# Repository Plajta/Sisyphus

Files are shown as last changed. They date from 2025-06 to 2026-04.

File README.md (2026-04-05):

# Sisyphus
This repository includes the hardware, firmware, chassis and documentation for our soundboard helping those who need it (or don't and want a thing that makes sounds).

Code for the firmware's web configurator (Lithos) can be found [here](https://github.com/Plajta/lithos).

## Key features
Built using open source software on widely documented hardware.

With RP2040 as it's beating heart and a nice crisp I2S DAC, it can (but probably won't be used to) do CD quality audio.

Built into a strudy, but slim and relatively lite 3D printed construction, held together by friction and screws for ease of repair and construction. (construction manual coming soon™)

## Directory structure
- [3D](3D/) - FreeCAD project, the [STLs](3D/STLs) subdirectory includes the exported files ready for 3D printing
- [PCBs](PCBs/) - Two KiCAD projects, one for Sisyphus's [mainboard](PCBs/sisyphus) and one for our own slim [RGB sensor module](PCBs/rgb_sensor)
- [src](src/) - The board's firmware, has it's own README, also usable on a Raspberry Pi Pico with a bit of configuration

## Licensing
All main directories have their own LICENSE files.

`3D` and `PCBs` are under CC-BY-SA. `src` is licensed under GPL3.
That means you can use the whole thing, or just a part of it in your commercial projects but must publically share your potential changes under the same license.

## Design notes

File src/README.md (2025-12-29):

# Sisyphus firmware
And RP2040 firmware built mainly for SisyFOSS boards. Includes a filesystem, color processing, USB stack with a custom protocol and a keyboard driver!

As this firmware is mainly built for custom boards it doesn't provide a good experience on the default Pico, but it still can run there.

A linker script is used for building, that allowed us to make a separate part of the flash JUST for the LittleFS filesystem. This means there is no way for data loss when upgrading firmware!

This repository consists of the following:
- [Audio](audio/) - takes care of audio and it's loading - built from [RPi's code](https://github.com/raspberrypi/pico-playground/blob/master/audio/sine_wave/sine_wave.c)
- [Battery management](battery/) - drivers for BMS chips
- [Boards](boards/) - headers for supported boards
- [Color](color/) - drivers for color sensors, color management, color LUT
- [Eternity](https://github.com/Plajta/eternity) - submodule - our custom built 3rd stage bootloader for the RP2040
- [Keyboard](keyboard/) - drivers for keyboard driver ICs
- [LittleFS](https://github.com/littlefs-project/littlefs) - submodule - an amazing small fail-safe filesystem for microcontrollers.
- [Protocol](protocol/) - a custom protocol for file management, diagnostics and setup
- [USB](usb/) - just TinyUSB headers
- [Util](util/) - misc stuff, setup for LittleFS for the RP2040, ARGB LED color indicator

## Installation
If you want to build the firmware yourself look [here](#building).

Github actions automatically builds the newest commit in three different versions:
1. Pico - meant for the RPi Pico - mainly for testing
2. Pico + Eternity - Also for the Pico, but includes our bootloader Eternity - also for testing
3. SisyFOSS - meant for the SisyFOSS β board, already includes Eternity
To install the normal Pico firmware just flash the `sisyphus.uf2`.

Builds with included Eternity can be flashed in two ways:
1. By flashing `combined.uf2` the normal way.
2. If your board already has Eternity on it, you can flash the `sisyphus.bin` file using the web interface included in this repository (WIP) or with [Eternity's flasher](https://github.com/Plajta/eternity/blob/main/protocol/flasher.py).

## Usage
The primary way of interacting with this firmware is using a [web interface](https://lithos.plajta.eu/) ([code](https://github.com/Plajta/lithos)).

If you want to take a look inside or just want to do it yourself, look inside in the [Protocol](protocol/) directory for its README and a bunch of interesting scripts.

## Building
Building was only tested on Linux, it might work elsewhere but only to a limited extent.

If you don't already know what software you need to build a pico-sdk project you can take a look at RPi's excellent docs [1](https://datasheets.raspberrypi.com/pico/getting-started-with-pico.pdf), [2](https://www.raspberrypi.com/documentation/microcontrollers/c_sdk.html#quick-start-your-own-project), for parts that talk about installing the toolchain.

First make sure you have your git submodules up to date. This will automatically clone [Eternity](https://github.com/Plajta/eternity)'s and [LittleFS](https://github.com/littlefs-project/littlefs)'s code.
```bash
git submodule update --init --recursive
```

Now create a `build` directory:
```bash
mkdir build
```
This is already where it gets a little bit complicated but stick with me. Since this firmware is mainly built for SisyFOSS boards we have to specifically say we want to build the firmware for them.
In the example below I picked the Sisyfoss β board. If you also want to include Eternity you have to specifically tell `cmake` to do that. Of course if you don't want either of those things just delete them.
```bash
cmake -DPICO_BOARD=plajta_sisyfoss_beta -DUSE_ETERNITY=ON ..
```
This should produce a bunch of binaries, but the ones you are interested in are either `sisyphus.uf2` or `combined.uf2` with `sisyphus.bin`. Take a look at how to work with them in the [Installation](#installation) part.

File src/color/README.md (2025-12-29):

# Color subsystem
This directory contains the color sensor initialization and color processing code.

The code in [color.c](./color.c) is basically just a split-off part of [main.c](../main.c) so it's more readable.

Sisyphus uses a [color LUT](#color-lut) for choosing which sound it should play. Each color in that LUT has its assigned letter, which is used to determine a part of the played file's name.
Each color also optionally can have a representation to be shown using the ARGB LED indicator. This is useful for user feedback.

# Adding a new sensor
When adding a new sensor, copy over an already existing one (eg. VEML3328) and edit over that.
Don't forget to edit the sensor's `CMakeLists.txt` and add it to [sensors/CMakeLists.txt](sensors/CMakeLists.txt).

# Color LUT
Colors and their name codes are described here in this format:
```
<H> <S> <V> <color_code> <color_representation>\n
```
The color is defined in a HSV format because it is better suited for color matching during detection.
H, S and V are in a DECIMAL format, and are space separated.

Color code can be any letter of the alphabet, be sure to save this file in ASCII so you don't get any unicode characters in there and accidentally break it.

The color representation is optional but highly recommended for enhanced user visual feedback. It is written as a standard RGB hexadecimal value.
If no color representation is defined, a muted white will be used.

The line MUST be terminated by a newline, it wouldn't break the program but it WILL skip the line.
Lines longer than 21 characters will get ignored because they cannot be valid.

An example of a valid LUT can look like this:
```
22 44 55 r AA0000
86 22 47 g
281 6 41 b 0000AA
220 32 73 c 00AAAA
335 18 51 m AA00AA
65 42 74 y AAAA00
```
Notice `g` is missing it's color representation, that is still valid but discouraged.

The values you define here are compared against the measured color by calculating the difference (`measured_value - defined_value`) for each channel.
The entry that has the smallest overall difference is selected as the match.
In the future we may choose to ignore some channels, such as S or V, if they prove unnecessary for detection.

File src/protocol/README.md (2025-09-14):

# Sisyphus Protocol
Sisyphus firmware has its own protocol to communicate with the web interface.

***All of the scripts contained in this directory have 3rd party dependencies, you have been warned.***

This protocol doesn't have to be used only with the interface, this directory includes a [reference Python implementation](protocol.py) of the protocol that you are free to use for your own endeavors.
It also includes [full documentation](PROTOCOL.md) of the protocol that should be enough for you to write your own client. If it's not enough yell at me in the issues.

If you just want to access the device, you can also use a [handy shell](shell.py).

You can also use the [audio conversion script](convert.py) for loading your audio on your device.

There is also a [script](color_graph.py) originally meant for debugging the color sensor.

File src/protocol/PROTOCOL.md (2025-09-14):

# Sisyphus Protocol Documentation

Data is transmitted in **chunks of up to 1024 bytes**.

Commands are sent as strings, fields separated by spaces, terminated by **EOT** (`0x04`) character.

The device responds according to the specific command.

Errors are reported with messages starting with `err`, and successful operations respond with `ack`.

On invalid arguments:
  ```
  err invalid arguments
  ```
On overflow of the command buffer (128 bytes set in [protocol.h](./protocol.h)):
  ```
  err command buffer overflow
  ```

A handy python shell to test things out is [here](./shell.py), it uses `PySerial` wrapped in a backend package [here](./protocol.py) and also requires `rich` for nice color output.

Protocol version is incremented when there is a breaking change, it will NOT get incremented when eg. a new field in [info](#info) is added to the end.

---

## Command List

- [ls](#ls) - List files
- [mv](#mv) - Move (rename) a file
- [push](#push) - Upload a file to the device
- [pull](#pull) - Download a file from the device
- [rm](#rm) - Remove a file
- [info](#info) - Get information about the device and firmware
- [measure](#measure) - Get a color measurement from the device's color sensor
- [play](#play) - Play an audio file
- [reset](#reset) - Reset the device into bootloader

---

## `ls`

List files in the filesystem.

**Usage:**
```
ls
```

**Device response:**

Each file or directory is listed on a separate line:

```
<name> <type> <size>
```

- `<name>` - file or directory name
- `<type>` - `f` (file) or `d` (directory)
- `<size>` - size in bytes (only present for files)

**Example:**
```
readme.txt f 1234
data f 456
folder d
```

Terminated by EOT.

**Errors:**
- `err cannot open root directory`

---

## `mv`

Rename or move a file.

**Usage:**
```
mv <source> <destination>
```

**Device response:**
- `ack` - on success
- `err file not found` - if source doesn't exist
- `err destination exists` - if destination already exists
- `err rename file` - on failure

---

## `push`

Upload a file to the device.

**Usage:**
```
push <filename> <size> <checksum>
```

- `<size>` - file size in bytes
- `<checksum>` - expected CRC32 checksum (unsigned integer)

**Protocol:**

1. After `push` command, device sends:
   ```
   ack
   ```
2. Send the file data in chunks.
   - After each chunk, **wait for device to send** `ack` **before sending the next chunk**.
3. After all bytes are sent:
   - Device calculates CRC32 and verifies it against `<checksum>`.

**Errors:**
- `err open file`
- `err timeout`
- `err write file`
- `err checksum mismatch` (file deleted automatically on checksum mismatch)

---

## `pull`

Download a file from the device.

**Usage:**
```
pull <filename>
```

**Protocol:**

1. Device responds:
   ```
   ack <size> <checksum>
   ```
   - `<size>` - file size in bytes
   - `<checksum>` - CRC32 checksum

2. Host must immediately reply:
   ```
   ack
   ```

3. Device starts sending the file data in chunks.

4. After each chunk:
   - Host must send `ack` back to device to receive the next chunk.

5. Host should verify the received data against the expected checksum.

**Errors:**
- `err cannot open file`
- `err calculate crc`
- `err timeout`

---

## `rm`

Remove a file.

**Usage:**
```
rm <filename>
```

**Device response:**
- `ack` - if deleted successfully
- `err file not found`
- `err delete file` - if deletion failed

---

## `info`

Lists information about the device.

**Usage:**
```
info
```

**Device response:**
```
<protocol> <device name> <git commit sha> <protocol version> <build date> <block count> <free block count> <block size> <uses eternity> <debug mode>
```

- `<protocol>` - Always `sisyphus`
- `<device name>` - Name of the device set by CMakeLists.txt
- `<git commit sha>` - Git commit SHA at compile time, when compiled from a repository with uncommitted changes `-dirty` gets appended behind it
- `<protocol version>` - Version of the protocol set in [protocol.h](./protocol.h)
- `<build date>` - Date and time of the firmware build in `YYYY-MM-DD,HH:MM:SS`
- `<block count>` - Number of blocks taken up by LittleFS - total size set in CMakeLists.txt
- `<free block count>` - Number of free/unused blocks in LittleFS
- `<block size>` - Size of each block of LittleFS
- `<uses eternity>` - If the FW was built with Eternity's bootloader
- `<debug mode>` - Shows if debug mode is on, if developing a user-friendly frontend make it VERY clear that this is NOT `true` so devs don't accidentally ship a debug device.

Terminated by a newline.

Example:

```
sisyphus 7b82af1-dirty 1 2025-05-05,00:45:02 256 2 4096 1
```

---

## `measure`

Get a color measurement from the device's color sensor. These are the actual values used for color detection with all color processing included.

**Usage:**
```
measure
```

**Device response:**
```
<hue> <saturation> <value> <clear>
```

- `<hue>` - 0-360 - hue in degrees
- `<saturation>` - 0-100 - saturation as a percentage
- `<value>` - 0-100 - value as a percentage
- `<clear>` - 0-255 - brightness in a 8 bit range

Terminated by a newline.

Example:

```
4 56 33 17
```

---

## `play`

Play an audio file stored on the device.

**Usage:**
```
play <filename>
```

**Response:**
- `ack` - if file played successfully
- `err file not found` - if the file does not exist

---

## `reset`

Resets the device into either the bootrom or Eternity, based on CMake configuration.

**Usage:**

```
reset
```

**Device response:**

* None (device resets and reboots into USB bootloader)

---

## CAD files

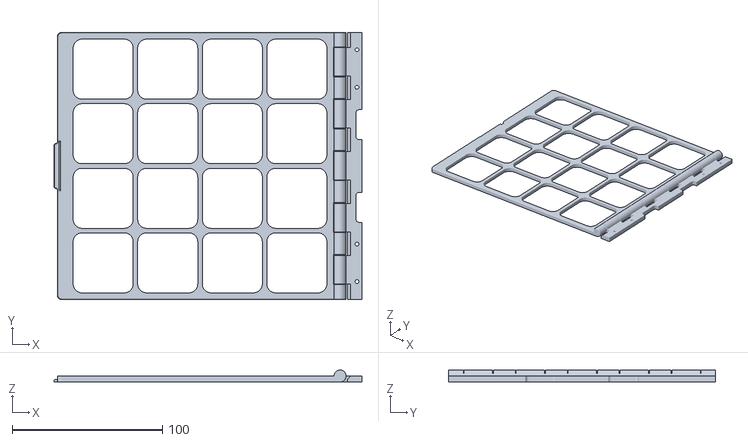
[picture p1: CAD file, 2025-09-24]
3D/STLs/sisyphus-Assembled-Hinge-Lid.stl
205.2 x 178.0 x 8.00

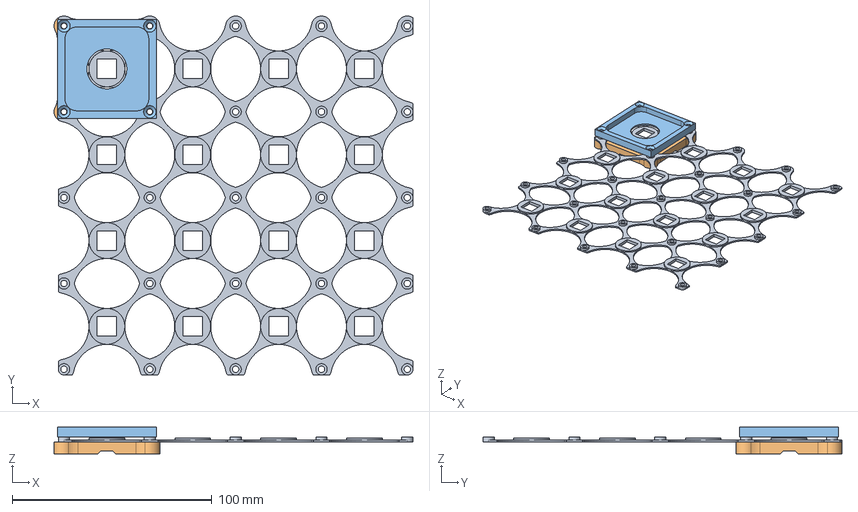
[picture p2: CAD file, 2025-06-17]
3D/sisyphus.FCStd
179.8 x 179.9 x 13.5 mm
Spring
Core
Top

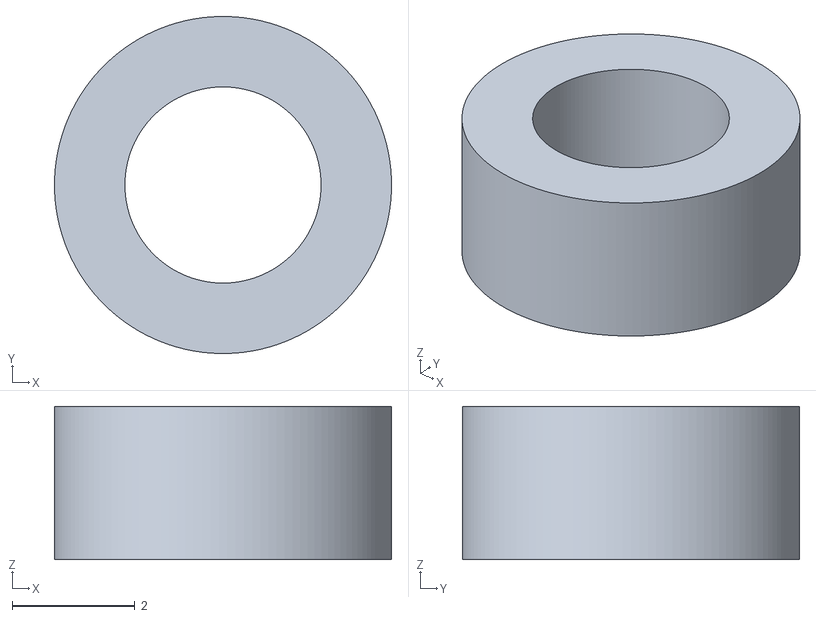
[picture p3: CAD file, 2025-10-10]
3D/STLs/sisyphus-M3_spacer.stl
5.50 x 5.50 x 2.50

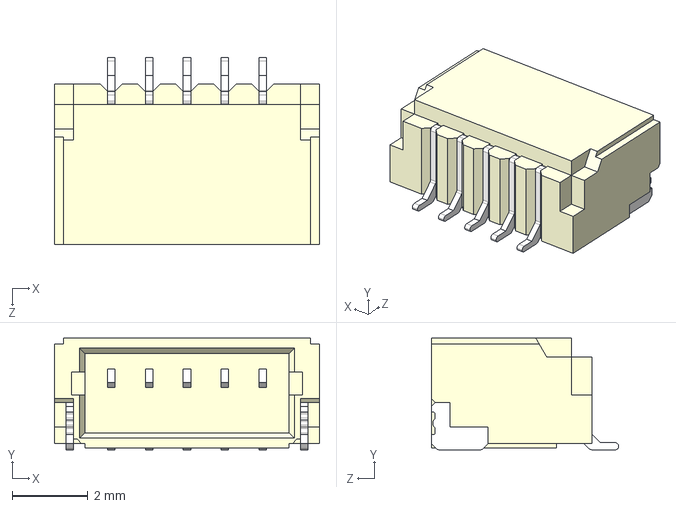
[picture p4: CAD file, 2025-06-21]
PCBs/rgb_sensor/rgb_sensor_3d/SM05B-SRSS-TB/SM05B-SRSS-TB.STEP
7.00 x 2.95 x 4.95 mm

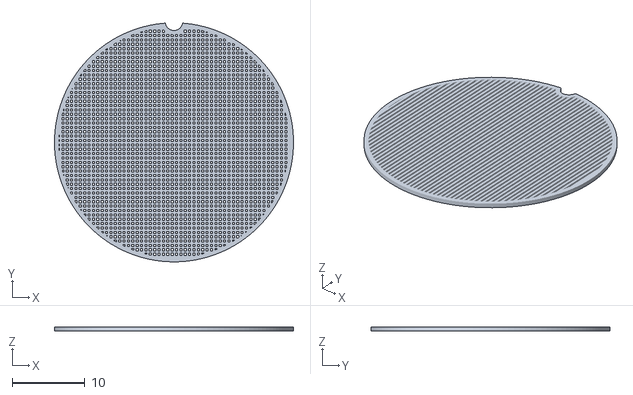
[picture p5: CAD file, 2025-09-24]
3D/STLs/sisyphus-Grille.stl
32.8 x 32.8 x 0.6

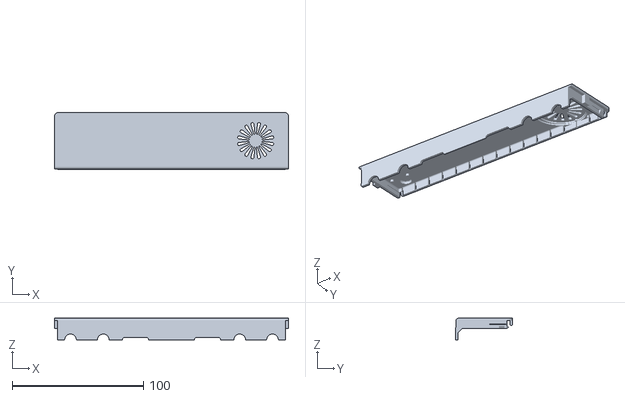
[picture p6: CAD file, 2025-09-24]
3D/STLs/sisyphus-Top_Cover.stl
178.4 x 43.7 x 16.6

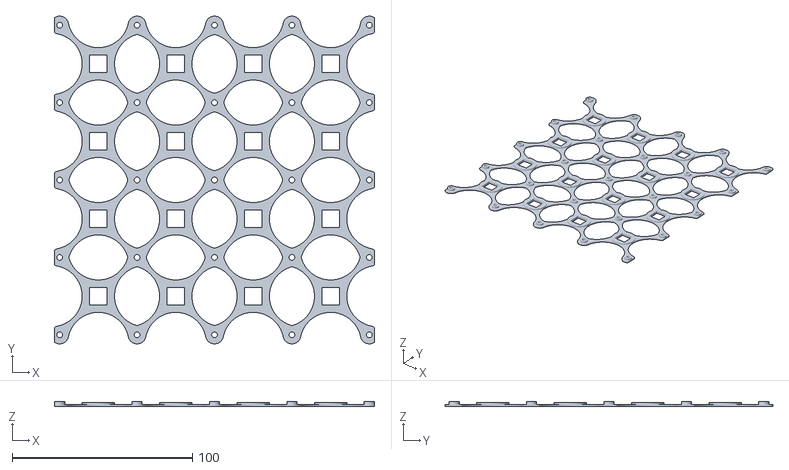
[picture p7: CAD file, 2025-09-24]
3D/STLs/sisyphus-Spring.stl
177.7 x 182.0 x 2.50

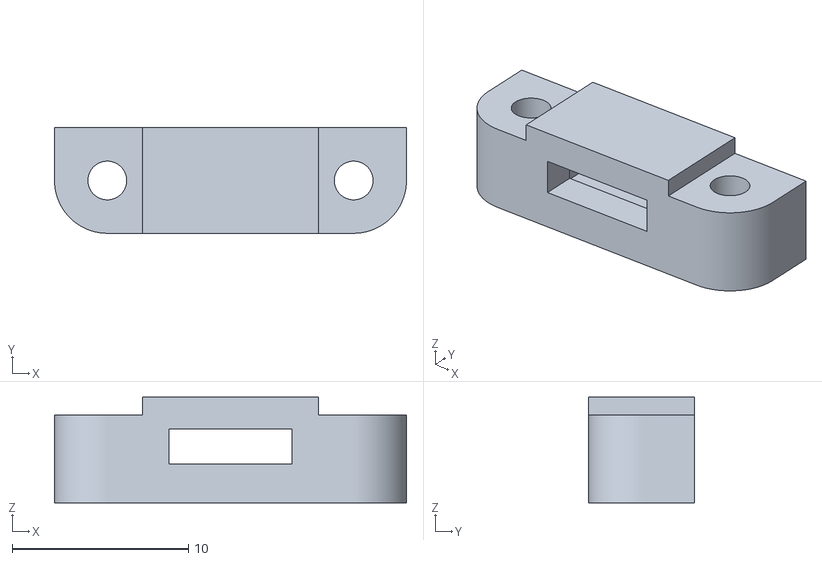
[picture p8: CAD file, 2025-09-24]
3D/STLs/sisyphus-Switch_holder.stl
20.0 x 6.00 x 6.00

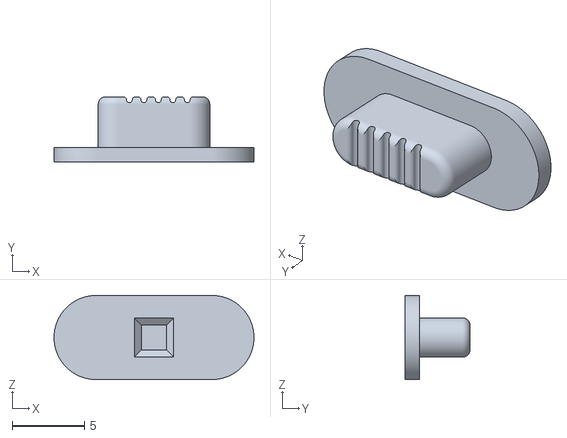
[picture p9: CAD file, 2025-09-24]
3D/STLs/sisyphus-Switch.stl
13.8 x 4.50 x 5.80

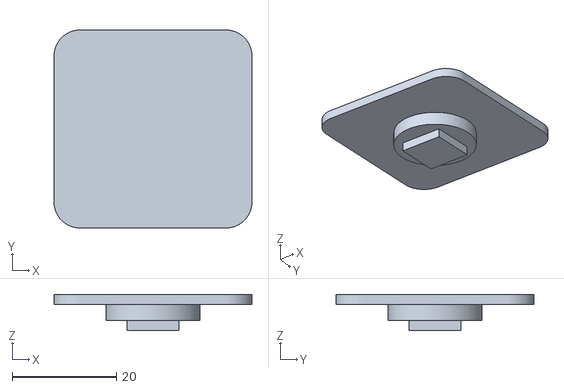
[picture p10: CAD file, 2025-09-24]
3D/STLs/sisyphus-Key_Cap.stl
38.0 x 38.0 x 7.00

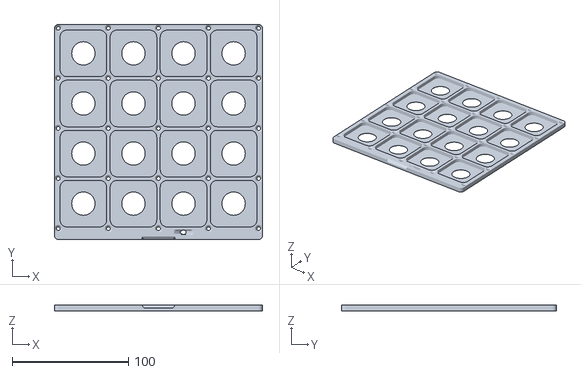
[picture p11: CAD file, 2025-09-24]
3D/STLs/sisyphus-Top.stl
178.6 x 184.6 x 5.00

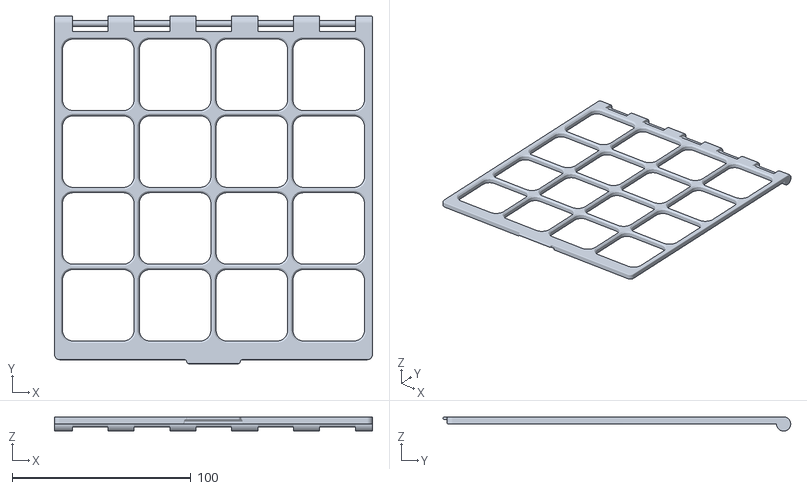
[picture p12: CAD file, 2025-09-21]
3D/STLs/sisyphus-Lid.stl
178.0 x 194.5 x 8.00

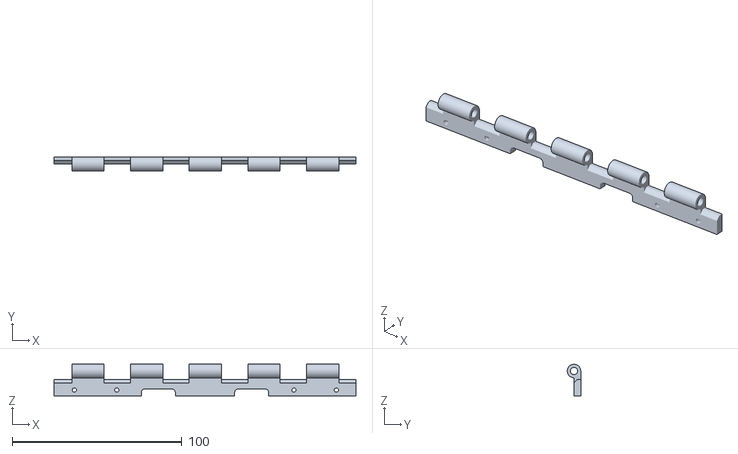
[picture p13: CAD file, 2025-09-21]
3D/STLs/sisyphus-Hinge.stl
178.0 x 8.00 x 18.6

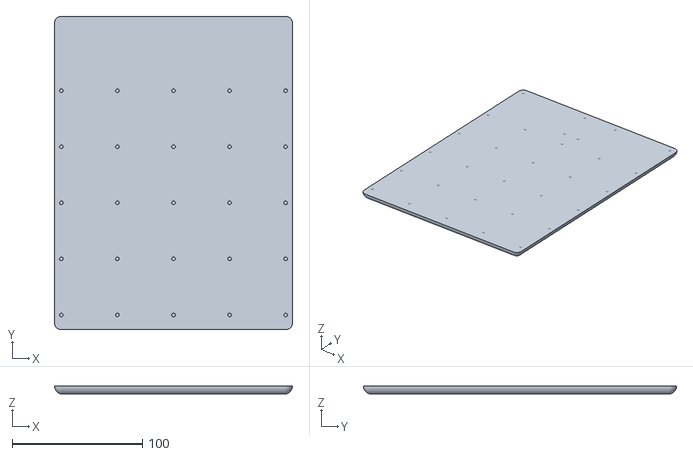
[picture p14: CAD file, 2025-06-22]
3D/STLs/sisyphus-Bottom.stl
182.5 x 240.2 x 6.50

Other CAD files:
PCBs/rgb_sensor/rgb_sensor_3d/VEML3328/80216oplga4l.stp

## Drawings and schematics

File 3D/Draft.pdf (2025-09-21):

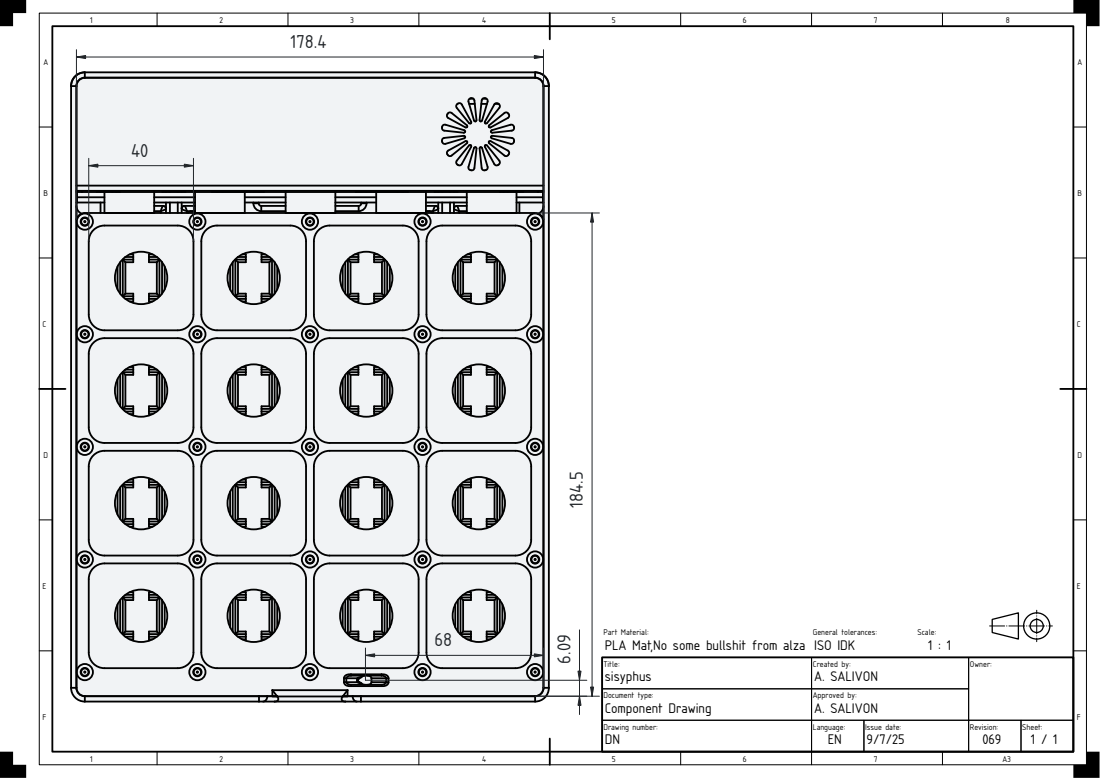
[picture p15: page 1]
Part Material:; General tolerances:; Scale:; PLA Mat,No some bullshit from alza ISO IDK

Title: sisyphus | Created by: A. SALIVON | Owner:

Document type: Component Drawing | Approved by: A. SALIVON

Drawing number: DN | Language: EN | Issue date: 9/7/25 | Revision: 069 | Sheet: 1 / 1

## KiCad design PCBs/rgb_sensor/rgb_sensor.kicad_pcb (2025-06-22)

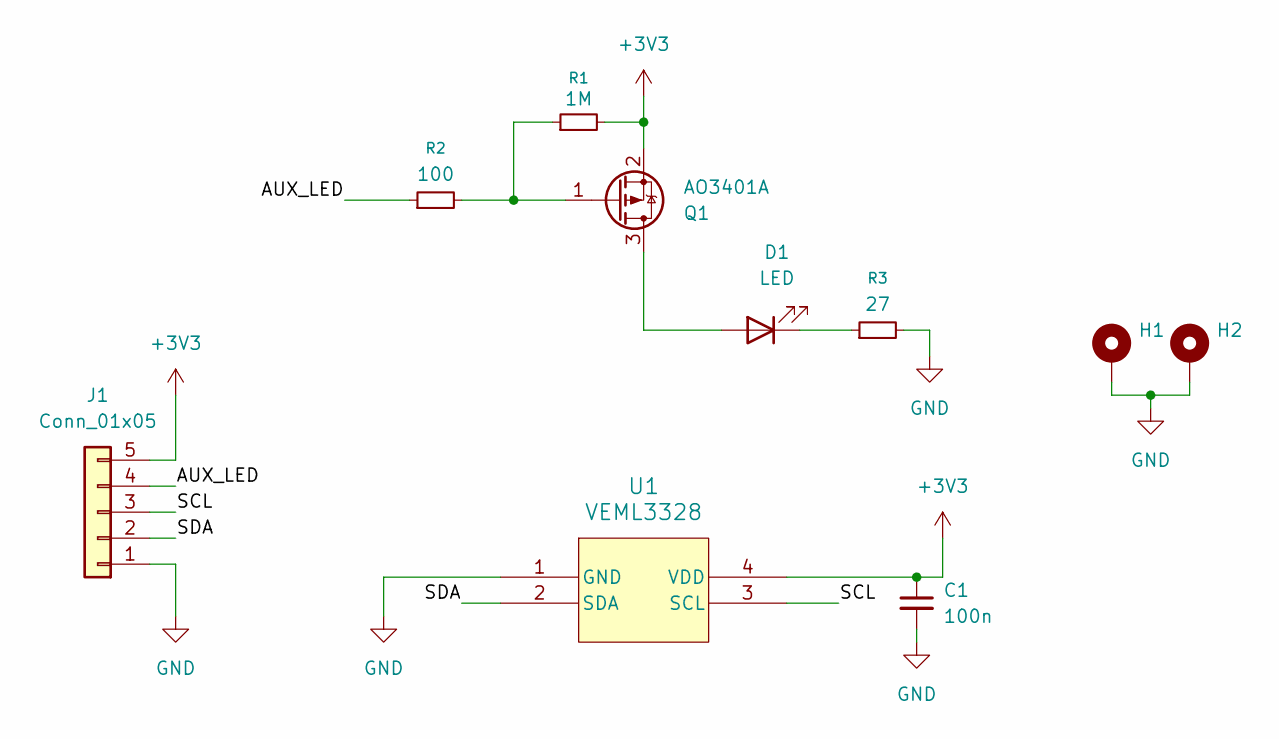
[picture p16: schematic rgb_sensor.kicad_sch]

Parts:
C1: 100n; C_0402_1005Metric
D1: LED; LED_0805_2012Metric
H1, H2: MountingHole_Pad; MountingHole_2.2mm_M2_Pad
J1: Conn_01x05; JST_SH_SM05B-SRSS-TB_1x05-1MP_P1.00mm_Horizontal
Q1: AO3401A; SOT-23
R1: 1M; R_0402_1005Metric
R2: 100; R_0402_1005Metric
R3: 27; R_0402_1005Metric
U1: VEML3328; SMD_L3328_VIS

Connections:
+3V3: C1.1, J1.5, Q1.2 (S), R1.2, U1.4 (VDD)
/AUX_LED: J1.4, R2.1
/SCL: J1.3, U1.3 (SCL)
/SDA: J1.2, U1.2 (SDA)
GND: C1.2, H1.1, H2.1, J1.1, R3.2, U1.1 (GND)
unnamed: D1.2 (A), Q1.3 (D)
unnamed: D1.1 (K), R3.1
unnamed: Q1.1 (G), R1.1, R2.2

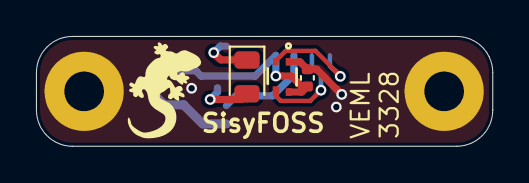
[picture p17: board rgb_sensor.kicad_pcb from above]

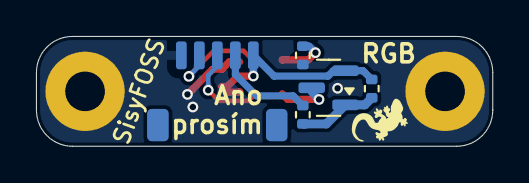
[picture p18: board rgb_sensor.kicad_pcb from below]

Board: 2 copper layers, 25.3 x 6.1 mm, 10 parts (5 on the bottom side), 8 nets.

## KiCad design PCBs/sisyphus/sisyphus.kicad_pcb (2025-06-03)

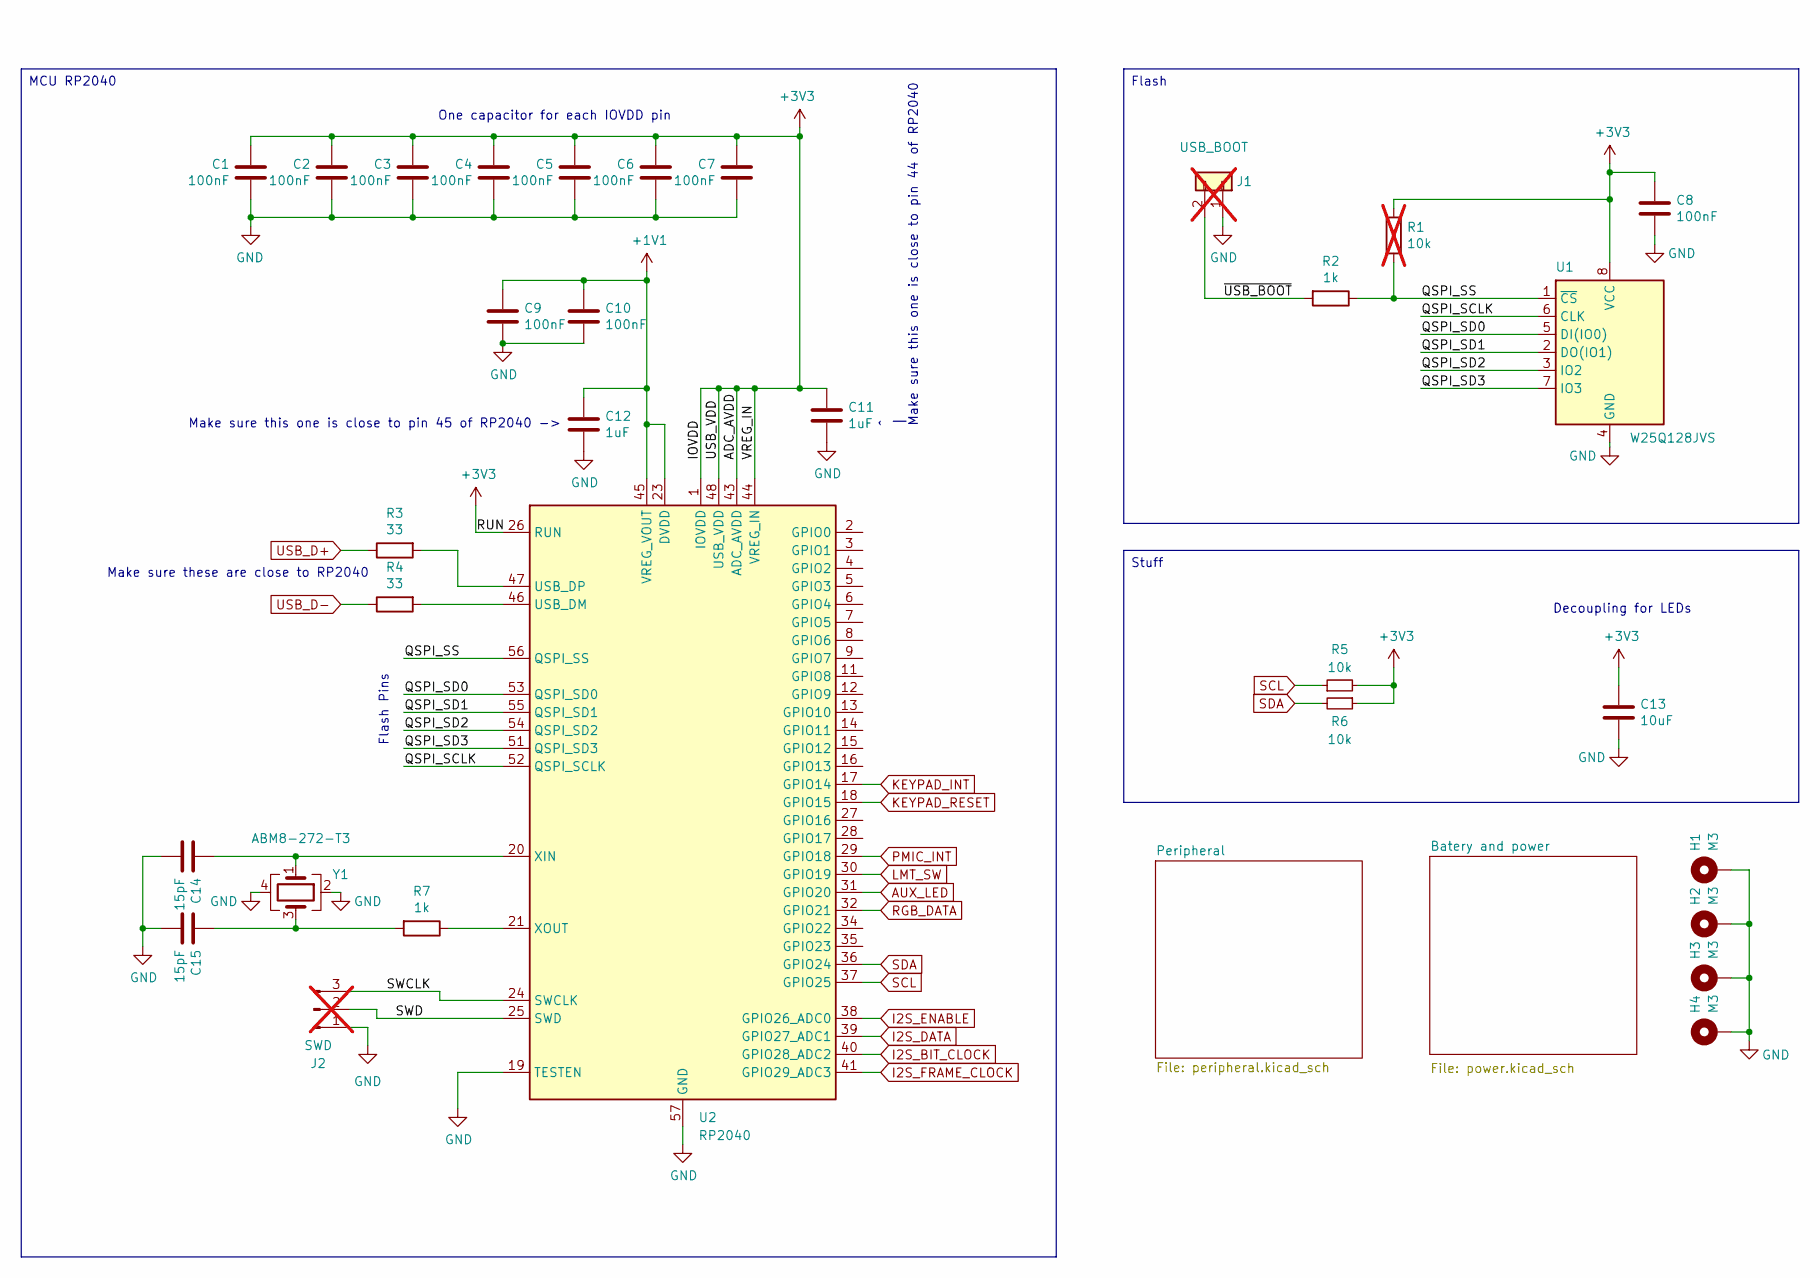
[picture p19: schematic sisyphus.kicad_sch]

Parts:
C1, C2, C3, C4, C5, C6, C7, C8, C9, C10: 100nF; C_0402_1005Metric
C11, C12: 1uF; C_0402_1005Metric
C13: 10uF; C_0402_1005Metric
C14, C15: 15pF; C_0402_1005Metric
H1, H2, H3, H4: M3; MountingHole_3.2mm_M3_ISO7380_Pad
J1: USB_BOOT; PinHeader_1x02_P2.54mm_Vertical; not fitted
J2: SWD; PinHeader_1x03_P2.54mm_Vertical; not fitted
R1: 10k; R_0402_1005Metric; not fitted
R2, R7: 1k; R_0402_1005Metric
R3, R4: 33; R_0402_1005Metric
R5, R6: 10k; R_0402_1005Metric
U1: W25Q128JVS; SOIC-8_5.23x5.23mm_P1.27mm
U2: RP2040; QFN-56-1EP_7x7mm_P0.4mm_EP3.2x3.2mm
Y1: ABM8-272-T3; Crystal_SMD_3225-4Pin_3.2x2.5mm

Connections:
+1V1: C9.1, C10.1, C12.1, U2.23 (DVDD), U2.45 (VREG_VOUT), U2.50 (DVDD)
+3V3: C1.1, C2.1, C3.1, C4.1, C5.1, C6.1, C7.1, C8.1, C11.1, C13.1, R1.1, R5.2, R6.1, U1.8 (VCC), U2.1 (IOVDD), U2.10 (IOVDD), U2.22 (IOVDD), U2.26 (RUN), U2.33 (IOVDD), U2.42 (IOVDD), U2.43 (ADC_AVDD), U2.44 (VREG_IN), U2.48 (USB_VDD), U2.49 (IOVDD); also elsewhere on the board
/QSPI_SCLK: U1.6 (CLK), U2.52 (QSPI_SCLK)
/QSPI_SD0: U1.5 (DI(IO0)), U2.53 (QSPI_SD0)
/QSPI_SD1: U1.2 (DO(IO1)), U2.55 (QSPI_SD1)
/QSPI_SD2: U1.3 (IO2), U2.54 (QSPI_SD2)
/QSPI_SD3: U1.7 (IO3), U2.51 (QSPI_SD3)
/QSPI_SS: R1.2, R2.1, U1.1 (~CS), U2.56 (QSPI_SS)
/SWCLK: J2.3, U2.24 (SWCLK)
/SWD: J2.2, U2.25 (SWD)
/~USB_BOOT: J1.2, R2.2
AUX_LED: U2.31 (GPIO20); also elsewhere on the board
GND: C1.2, C2.2, C3.2, C4.2, C5.2, C6.2, C7.2, C8.2, C9.2, C10.2, C11.2, C12.2, C13.2, C14.2, C15.2, H1.1, H2.1, H3.1, H4.1, J1.1, J2.1, U1.4 (GND), U2.19 (TESTEN), U2.57 (GND), Y1.2, Y1.4; also elsewhere on the board
I2S_BIT_CLOCK: U2.40 (GPIO28_ADC2); also elsewhere on the board
I2S_DATA: U2.39 (GPIO27_ADC1); also elsewhere on the board
I2S_ENABLE: U2.38 (GPIO26_ADC0); also elsewhere on the board
I2S_FRAME_CLOCK: U2.41 (GPIO29_ADC3); also elsewhere on the board
KEYPAD_INT: U2.17 (GPIO14); also elsewhere on the board
KEYPAD_RESET: U2.18 (GPIO15); also elsewhere on the board
LMT_SW: U2.30 (GPIO19); also elsewhere on the board
unnamed: C15.1, R7.2, Y1.3
unnamed: R4.2, U2.46 (USB_DM)
unnamed: R3.2, U2.47 (USB_DP)
unnamed: C14.1, U2.20 (XIN), Y1.1
unnamed: R7.1, U2.21 (XOUT)
PMIC_INT: U2.29 (GPIO18); also elsewhere on the board
RGB_DATA: U2.32 (GPIO21); also elsewhere on the board
SCL: R5.1, U2.37 (GPIO25); also elsewhere on the board
SDA: R6.2, U2.36 (GPIO24); also elsewhere on the board
USB_D+: R3.1; also elsewhere on the board
USB_D-: R4.1; also elsewhere on the board

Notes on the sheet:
Make sure this one is close to pin 45 of RP2040 ->
Decoupling for LEDs
Make sure these are close to RP2040
One capacitor for each IOVDD pin
^ | Make sure this one is close to pin 44 of RP2040
Flash Pins
Flash
MCU RP2040
Stuff

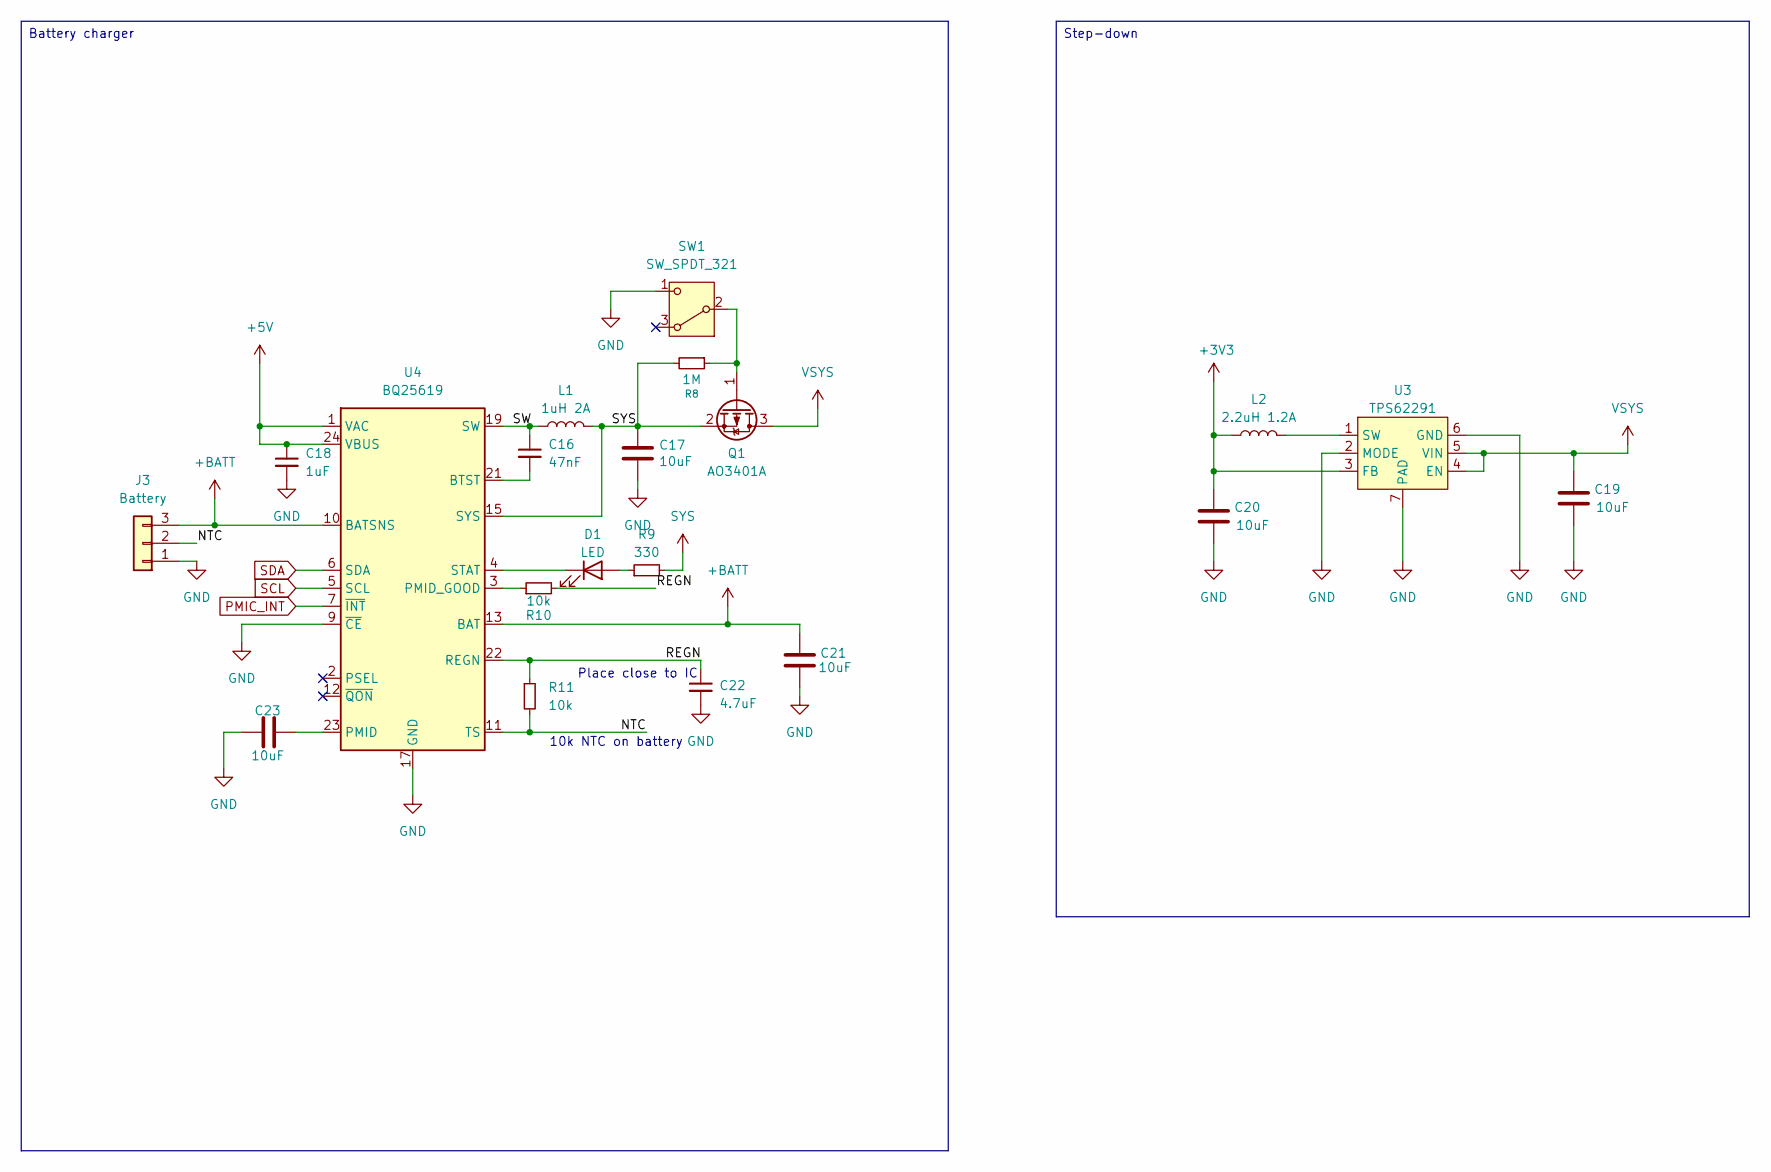
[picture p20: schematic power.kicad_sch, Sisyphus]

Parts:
C16: 47nF; C_0402_1005Metric
C17, C19, C20, C21, C23: 10uF; C_0402_1005Metric
C18: 1uF; C_0402_1005Metric
C22: 4.7uF; C_0402_1005Metric
D1: LED; LED_0603_1608Metric
J3: Battery; JST_PH_S3B-PH-SM4-TB_1x03-1MP_P2.00mm_Horizontal
L1: 1uH 2A; L_0603_1608Metric
L2: 2.2uH 1.2A; L_0805_2012Metric
Q1: AO3401A; SOT-23
R8: 1M; R_0402_1005Metric
R9: 330; R_0402_1005Metric
R10, R11: 10k; R_0402_1005Metric
SW1: SW_SPDT_321; PinHeader_1x03_P2.54mm_Vertical
U3: TPS62291; WSON-6-1EP_2x2mm_P0.65mm_EP1x1.6mm_ThermalVias
U4: BQ25619; Texas_RTW_WQFN-24-1EP_4x4mm_P0.5mm_EP2.7x2.7mm_ThermalVias

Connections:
+3V3: C20.1, L2.1, U3.3 (FB); also elsewhere on the board
+5V: C18.1, U4.1 (VAC), U4.24 (VBUS); also elsewhere on the board
+BATT: C21.1, J3.3, U4.10 (BATSNS), U4.13 (BAT), U4.14 (BAT)
/Batery and power/NTC: J3.2, R11.2, U4.11 (TS)
/Batery and power/REGN: C22.1, R10.2, R11.1, U4.22 (REGN)
/Batery and power/SW: C16.1, L1.1, U4.19 (SW), U4.20 (SW)
GND: C17.2, C18.2, C19.2, C20.2, C21.2, C22.2, C23.1, J3.1, SW1.1 (C), U3.2 (MODE), U3.6 (GND), U3.7 (PAD), U4.9 (~CE), U4.17 (GND), U4.18 (GND), U4.25 (GND); also elsewhere on the board
unnamed: D1.2 (A), R9.1
unnamed: D1.1 (K), U4.4 (STAT)
unnamed: Q1.1 (G), R8.1, SW1.2 (B)
unnamed: L2.2, U3.1 (SW)
unnamed: C16.2, U4.21 (BTST)
unnamed: C23.2, U4.23 (PMID)
unnamed: R10.1, U4.3 (PMID_GOOD)
PMIC_INT: U4.7 (~INT); also elsewhere on the board
SCL: U4.5 (SCL); also elsewhere on the board
SDA: U4.6 (SDA); also elsewhere on the board
SYS: C17.1, L1.2, Q1.2 (S), R8.2, R9.2, U4.15 (SYS), U4.16 (SYS)
VSYS: C19.1, Q1.3 (D), U3.4 (EN), U3.5 (VIN); also elsewhere on the board

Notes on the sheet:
Place close to IC
10k NTC on battery
Step-down
Battery charger

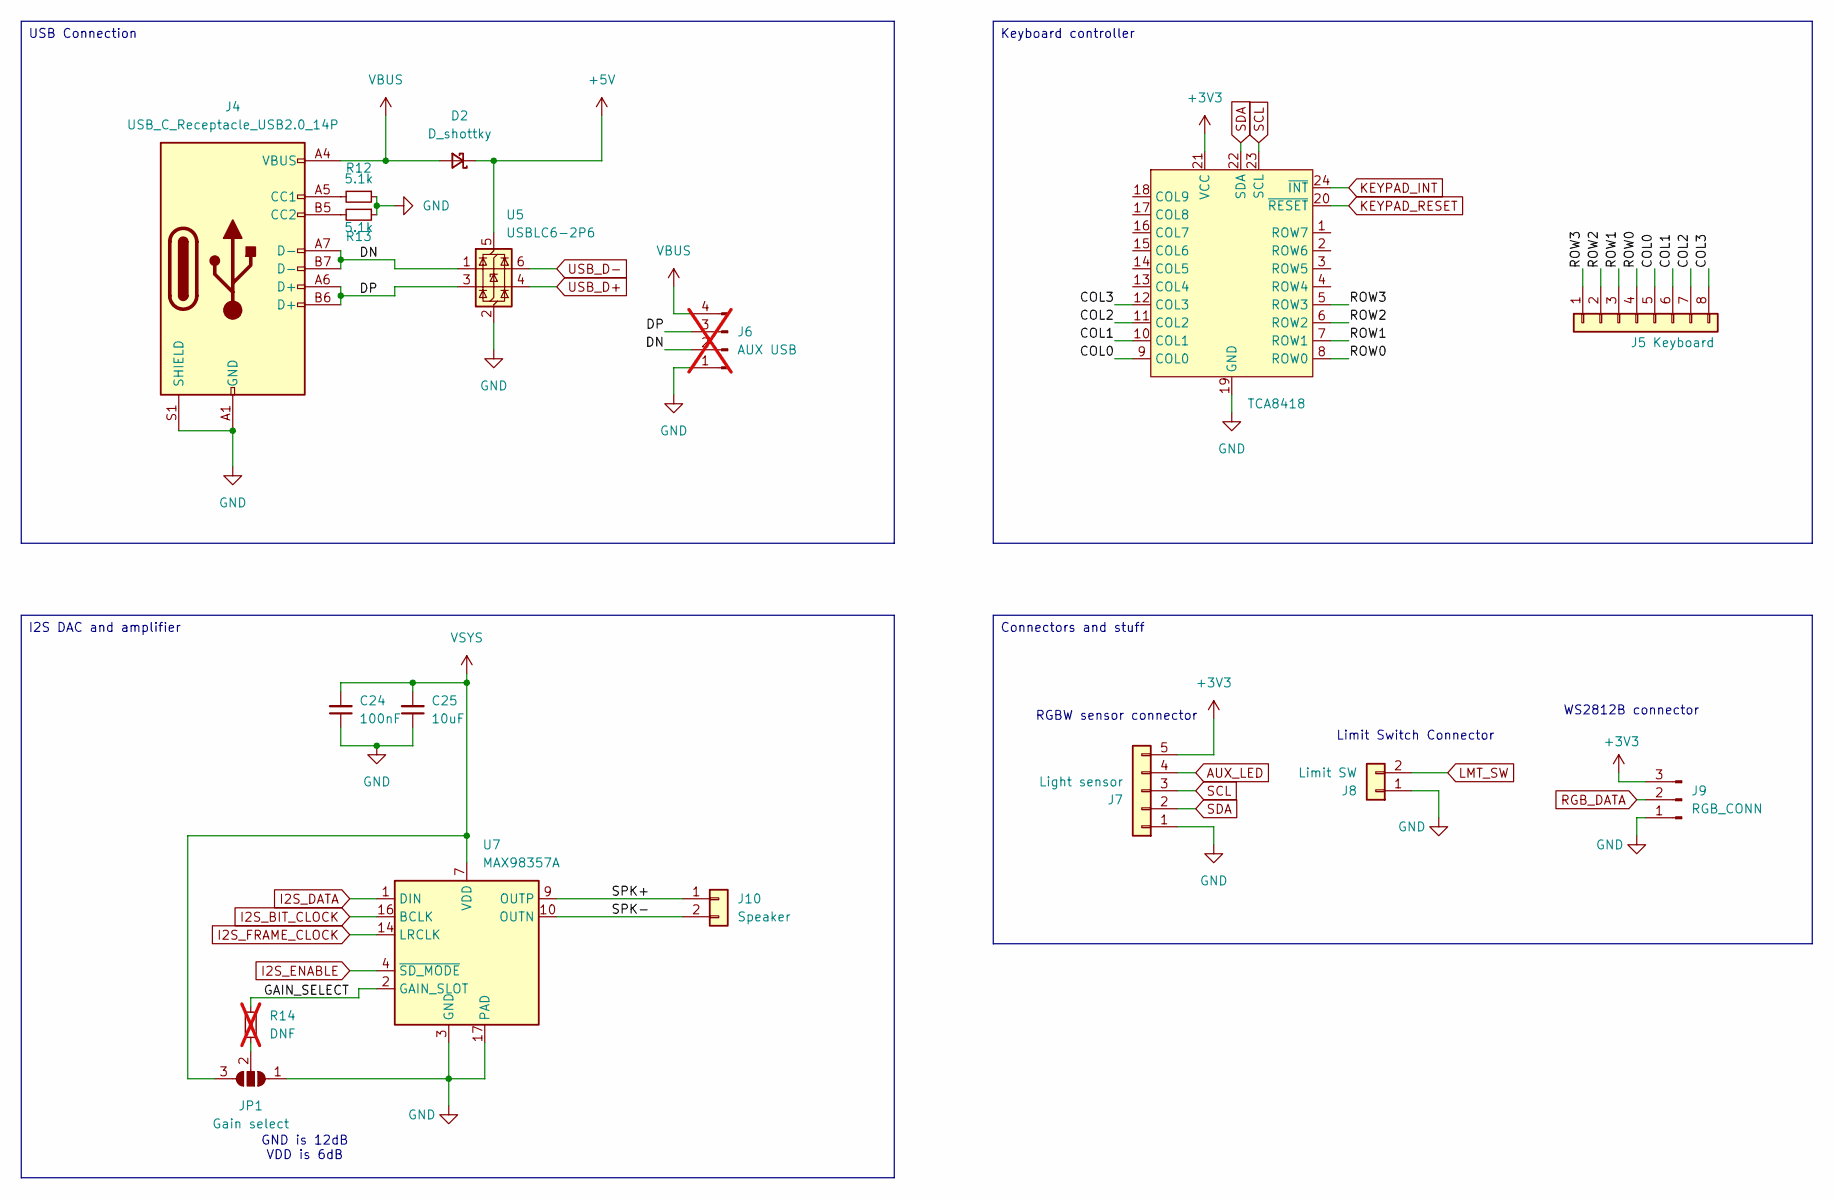
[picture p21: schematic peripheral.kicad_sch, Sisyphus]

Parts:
C24: 100nF; C_0402_1005Metric
C25: 10uF; C_0402_1005Metric
D2: D_shottky; D_SOD-123
J4: USB_C_Receptacle_USB2.0_14P; USB_C_Receptacle_G-Switch_GT-USB-7010ASV
J5: Keyboard; JST_XH_S8B-XH-A_1x08_P2.50mm_Horizontal
J6: AUX USB; PinHeader_1x04_P2.54mm_Vertical; not fitted
J7: Light sensor; JST_XH_S5B-XH-A_1x05_P2.50mm_Horizontal
J8: Limit SW; PinSocket_1x02_P2.54mm_Vertical
J9: RGB_CONN; PinHeader_1x03_P2.54mm_Vertical
J10: Speaker; PinHeader_1x02_P2.54mm_Vertical
JP1: Gain select; SolderJumper-3_P1.3mm_Open_RoundedPad1.0x1.5mm
R12, R13: 5.1k; R_0402_1005Metric
R14: DNF; R_0402_1005Metric; not fitted
U5: USBLC6-2P6; SOT-666
U6: TCA8418; WQFN-24-1EP_4x4mm_P0.5mm_EP2.45x2.45mm
U7: MAX98357A; TQFN-16-1EP_3x3mm_P0.5mm_EP1.23x1.23mm

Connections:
+3V3: J7.5, J9.3, U6.21 (VCC); also elsewhere on the board
+5V: D2.1 (K), U5.5 (VBUS); also elsewhere on the board
/Peripheral/COL0: J5.5, U6.9 (COL0)
/Peripheral/COL1: J5.6, U6.10 (COL1)
/Peripheral/COL2: J5.7, U6.11 (COL2)
/Peripheral/COL3: J5.8, U6.12 (COL3)
/Peripheral/DN: J4.A7 (D-), J4.B7 (D-), J6.2, U5.1 (I/O1)
/Peripheral/DP: J4.A6 (D+), J4.B6 (D+), J6.3, U5.3 (I/O2)
/Peripheral/GAIN_SELECT: R14.1, U7.2 (GAIN_SLOT)
/Peripheral/ROW0: J5.4, U6.8 (ROW0)
/Peripheral/ROW1: J5.3, U6.7 (ROW1)
/Peripheral/ROW2: J5.2, U6.6 (ROW2)
/Peripheral/ROW3: J5.1, U6.5 (ROW3)
/Peripheral/SPK+: J10.1, U7.9 (OUTP)
/Peripheral/SPK-: J10.2, U7.10 (OUTN)
AUX_LED: J7.4; also elsewhere on the board
GND: C24.1, C25.1, J4.A1 (GND), J4.A12 (GND), J4.B1 (GND), J4.B12 (GND), J4.S1 (SHIELD), J6.1, J7.1, J8.1, J9.1, JP1.1 (A), R12.1, R13.1, U5.2 (GND), U6.19 (GND), U6.25 (PAD), U7.3 (GND), U7.11 (GND), U7.15 (GND), U7.17 (PAD); also elsewhere on the board
I2S_BIT_CLOCK: U7.16 (BCLK); also elsewhere on the board
I2S_DATA: U7.1 (DIN); also elsewhere on the board
I2S_ENABLE: U7.4 (~SD_MODE); also elsewhere on the board
I2S_FRAME_CLOCK: U7.14 (LRCLK); also elsewhere on the board
KEYPAD_INT: U6.24 (~INT); also elsewhere on the board
KEYPAD_RESET: U6.20 (~RESET); also elsewhere on the board
LMT_SW: J8.2; also elsewhere on the board
unnamed: J4.A5 (CC1), R12.2
unnamed: J4.B5 (CC2), R13.2
unnamed: JP1.2 (C), R14.2
RGB_DATA: J9.2; also elsewhere on the board
SCL: J7.3, U6.23 (SCL); also elsewhere on the board
SDA: J7.2, U6.22 (SDA); also elsewhere on the board
USB_D+: U5.4 (I/O2); also elsewhere on the board
USB_D-: U5.6 (I/O1); also elsewhere on the board
VBUS: D2.2 (A), J4.A4 (VBUS), J4.A9 (VBUS), J4.B4 (VBUS), J4.B9 (VBUS), J6.4
VSYS: C24.2, C25.2, JP1.3 (B), U7.7 (VDD), U7.8 (VDD); also elsewhere on the board

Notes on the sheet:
GND is 12dB VDD is 6dB
WS2812B connector
Limit Switch Connector
RGBW sensor connector
Connectors and stuff
Keyboard controller
I2S DAC and amplifier
USB Connection

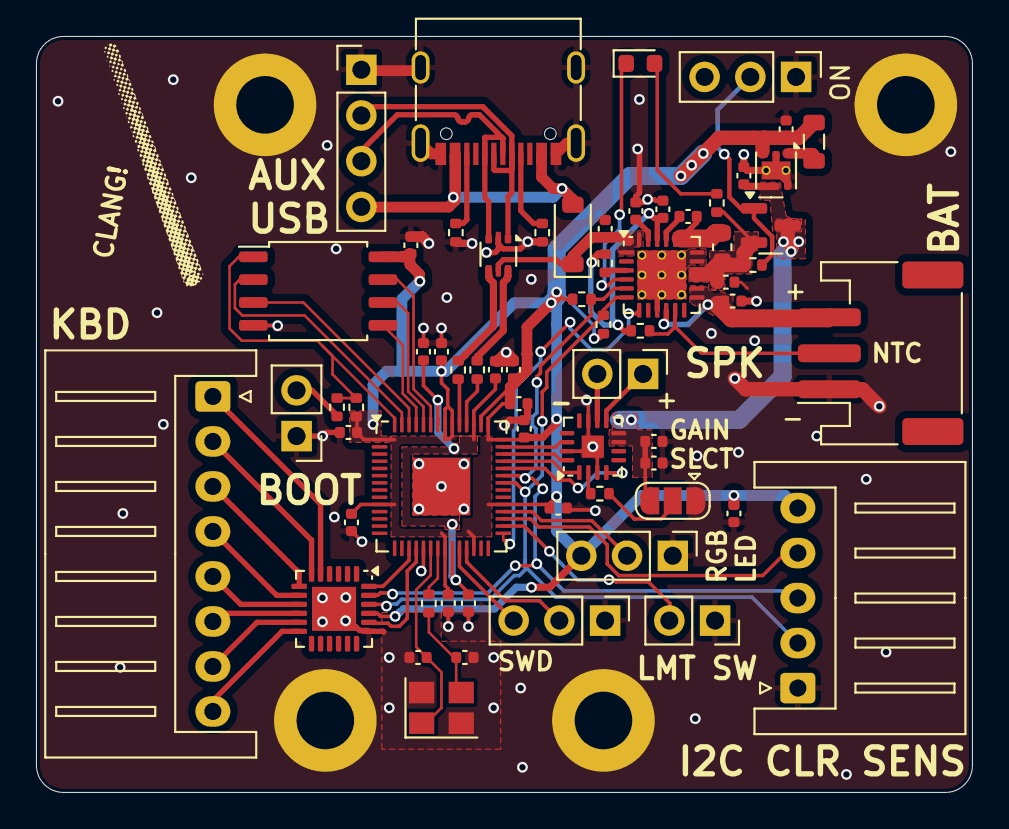
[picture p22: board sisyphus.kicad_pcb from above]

Board: 2 copper layers, 52.0 x 42.0 mm, 68 parts (0 on the bottom side), 62 nets.

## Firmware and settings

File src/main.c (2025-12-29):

#include <hardware/gpio.h>
#include <pico/error.h>
#include <pico/time.h>
#include <stdbool.h>
#include <stdio.h>
#include <bsp/board_api.h>
#include "bq25619.h"
#include "class/cdc/cdc_device.h"
#include "pico/binary_info.h" // IWYU pragma: keep
#include <tusb.h>
#include "protocol.h"
#include "hardware/i2c.h"
#include "audio.h"
#include "color.h"
#include "tca8418.h"
#include "ws2812.h"
#include "lightshow.h"

#include "littlefs-pico.h"

#define BUTTON_PIN 14

#ifdef SISYFOSS_I2S_ENABLE
bi_decl(bi_1pin_with_name(SISYFOSS_I2S_ENABLE, "I2S ENABLE"));
#endif

#if !defined(i2c_default) || !defined(PICO_DEFAULT_I2C_SDA_PIN) || !defined(PICO_DEFAULT_I2C_SCL_PIN)
#error Sisyphus requires a board with I2C pins
#endif

lfs_t lfs;

volatile bool wakeup = false;
volatile uint8_t button_index = 0;

volatile bool trigger_color_scan = false;
volatile bool trigger_audio = false;

static repeating_timer_t usb_timer;

struct color_matched_entry matched_color;
bool matched_color_valid = false;

i2c_inst_t *sisyfoss_i2c_inst = i2c_default;

static bool usb_background_task(repeating_timer_t *rt) {
    (void) rt;
    tud_task();  // TinyUSB background task
    return true; // Keep repeating
}

// Taken out so we can call it before loop and on trigger
void scan_color(){
    color_measurement color;
    color_read_sensor(&color);
    // 200 was just a shot i guessed and it seems to work, should probably be lowered
    // 170 is measured specifically for Sisyfoss's experimental 3D model right now, should be treated as a test number
    matched_color_valid = (color_lut_get_entry(&color, &matched_color, 200, 170) == PICO_OK);

    #ifdef PICO_DEFAULT_WS2812_PIN
    if (matched_color_valid){
        static lightshow_quartic_fade_state_t lightshow_state;

        lightshow_state.t = 0;
        lightshow_state.duration = 0.5;
        lightshow_state.reverse = false;
        lightshow_state.start_next_reversed = true;
        lightshow_state.base_color = matched_color.led_color_representation;

        lightshow_fade_setup(&lightshow_state);
    }
    #endif
}

void keyboard_interrupt() {
    if(!tca8418_k_int_available(sisyfoss_i2c_inst)){
        return;
    }

    uint8_t kbd_events = tca8418_num_events(sisyfoss_i2c_inst);

    // Re-check INT_STAT here (important per documentation)
    if (!tca8418_k_int_available(sisyfoss_i2c_inst)) {
        return;
    }

    uint8_t value;
    bool pressed;

    while (tca8418_num_events(sisyfoss_i2c_inst) > 0) {
        tca8418_get_key_from_fifo(sisyfoss_i2c_inst, &value, &pressed);
        button_index = value;
        if (pressed && !tud_cdc_connected()){
            wakeup = true;
            trigger_audio = true;
        }
    }

    // Clear the KE_INT interrupt bit by writing 1
    tca8418_k_int_reset(sisyfoss_i2c_inst);
}

void gpio_irq_dispatcher(uint gpio, uint32_t events){
    if (gpio == SISYFOSS_LID_DETECT && (events & GPIO_IRQ_EDGE_FALL)) {
        wakeup = true;
        trigger_color_scan = true;
    }
    else if (gpio == SISYFOSS_LID_DETECT && (events & GPIO_IRQ_EDGE_RISE)) {
        matched_color_valid = false;
    }
    #ifndef SISYFOSS_HAS_KEYBOARD_CONTROLLER
    else if (gpio == BUTTON_PIN && (events & GPIO_IRQ_EDGE_FALL)) {
        if(!tud_cdc_connected()){
            wakeup = true;
            button_index = 0;
        }
    }
    #else
    else if (gpio == SISYFOSS_KEYBOARD_INTERRUPT && (events & GPIO_IRQ_EDGE_FALL)) {
        keyboard_interrupt();
    }
    #endif
}

int main() {
    #ifdef PICO_DEFAULT_WS2812_PIN
    // First of all get the status LED, so errors can be shown
    int err = ws2812_init(PICO_DEFAULT_WS2812_PIN);
    hard_assert(err);
    #endif

    i2c_init(sisyfoss_i2c_inst, 100 * 1000);
    gpio_set_function(PICO_DEFAULT_I2C_SDA_PIN, GPIO_FUNC_I2C);
    gpio_set_function(PICO_DEFAULT_I2C_SCL_PIN, GPIO_FUNC_I2C);
    gpio_pull_up(PICO_DEFAULT_I2C_SDA_PIN);
    gpio_pull_up(PICO_DEFAULT_I2C_SCL_PIN);
    bi_decl(bi_2pins_with_func(PICO_DEFAULT_I2C_SDA_PIN, PICO_DEFAULT_I2C_SCL_PIN, GPIO_FUNC_I2C));
    bq25619_init(sisyfoss_i2c_inst); // init charger before all due safety reasons

    tusb_init();
    // Run tud_task every millisecond just like pico_stdio would do
    add_repeating_timer_ms(1, usb_background_task, NULL, &usb_timer);

    #ifdef SISYFOSS_I2S_ENABLE
    gpio_init(SISYFOSS_I2S_ENABLE);
    gpio_set_dir(SISYFOSS_I2S_ENABLE, GPIO_OUT);
    gpio_put(SISYFOSS_I2S_ENABLE, 1);
    #endif

    err = pico_lfs_init(&lfs);

    if (err) {
        sleep_ms(5000);
        return 0; // Todo add a color indicated error
    }

    init_audio();
    err = color_init();

    gpio_set_irq_callback(&gpio_irq_dispatcher);

    #ifndef SISYFOSS_HAS_KEYBOARD_CONTROLLER
    gpio_init(BUTTON_PIN);
    gpio_set_dir(BUTTON_PIN, GPIO_IN);
    gpio_pull_up(BUTTON_PIN);
    gpio_set_irq_enabled(BUTTON_PIN, GPIO_IRQ_EDGE_FALL, true);
    #else
    tca8418_init(sisyfoss_i2c_inst);
    tca8418_setup_keyboard(sisyfoss_i2c_inst, 0b1111, 0b1111);
    tca8418_setup_interrupt(&keyboard_interrupt);
    #endif

    #ifdef SISYFOSS_LID_DETECT
    gpio_init(SISYFOSS_LID_DETECT);
    gpio_set_dir(SISYFOSS_LID_DETECT, GPIO_IN);
    gpio_pull_up(SISYFOSS_LID_DETECT);
    gpio_set_irq_enabled(SISYFOSS_LID_DETECT, GPIO_IRQ_EDGE_FALL | GPIO_IRQ_EDGE_RISE, true);
    #endif

    // Enable GPIO IRQs
    irq_set_enabled(IO_IRQ_BANK0, true);

    scan_color();

    while (true) {
        // Check for USB-CDC connection
        if (tud_cdc_connected()) {
            #ifdef SISYPHUS_DEBUG
            char buf[128];
            // Get the things you wanna debug here
            snprintf(buf, sizeof(buf), "DEBUG MODE ON, DO NOT SHIP!!!\r\n");
            tud_cdc_write_str(buf);
            tud_cdc_write_flush();
            snprintf(buf, sizeof(buf), "DEBUG DATA: \r\n"); //add your debug data here
            tud_cdc_write_str(buf);
            tud_cdc_write_flush();
            #endif
            protocol_loop();
        }

        // If not connected and no button pressed, go to sleep
        while (!tud_cdc_connected() && !wakeup) {
            __wfi(); // Low-power wait for interrupt
        }

        if (wakeup) {
            wakeup = false;

            if (trigger_color_scan) {
                trigger_color_scan = false;
                scan_color();
            }

            if(trigger_audio){
                trigger_audio = false;
                if (matched_color_valid){
                    char filename[16]; // 16 should be enough
                    snprintf(filename, sizeof(filename), "%c_%d.wav", matched_color.name, button_index);
                    play_audio(filename);
                }
            }
        }
    }


    return 0;
}

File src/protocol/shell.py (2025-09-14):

#!/usr/bin/env python3
import cmd
import readline
import glob
import os
import sys
import protocol
from rich.console import Console
from rich.progress import Progress

console = Console()

class DeviceShell(cmd.Cmd):
    prompt = "\033[1;36mSisyphus>\033[0m "

    def __init__(self, device):
        super().__init__()
        self.device = device
        # cache remote files for completion
        self.autofill_remote_refresh()

    def preloop(self):
        readline.parse_and_bind('tab: complete')

    def autofill_remote_refresh(self):
        files = self.device.ls()
        remote_files = []
        for file in files:
            remote_files.append(file.name)
        self.remote_files = remote_files

    def do_ls(self, arg):
        "ls                List remote files"
        files = self.device.ls()
        console.print("[red]<Filename>[/red] [green]<Size in bytes>[/green]")

        remote_files = [] # Update it anyway, just in case
        for file in files:
            remote_files.append(file.name) # Update it anyway, just in case

            console.print(f"[red]{file.name}[/red] [green]{file.size}[/green]")
        self.remote_files = remote_files

    def complete_ls(self, text, line, begidx, endidx):
        return []  # no args

    def do_rm(self, arg):
        "rm <filename>     Remove remote file"
        if not arg:
            console.print("[bold red]Usage: rm <filename>[/bold red]")
        elif arg not in self.remote_files:
            console.print(f"[bold red]No such file: {arg}[/bold red]")
        else:
            status, resp = self.device.rm(arg)
            if status:
                console.print(f"[green]File [bold]{arg}[/bold] removed")
            else:
                console.print(f"[bold red]Error: {resp}[/bold red]")
                self.autofill_remote_refresh()

    def complete_rm(self, text, line, begidx, endidx):
        return [f for f in self.remote_files if f.startswith(text)]

    def do_mv(self, arg):
        "mv <old> <new>    Rename remote file"

        parts = arg.split()
        if len(parts) != 2:
            console.print("[bold red]Usage: mv <old> <new>[/bold red]")
            return
        old, new = parts

        if old not in self.remote_files:
            console.print(f"[bold red]No such file: {old}[/bold red]")
            return

        status, resp = self.device.mv(old, new)
        if status:
            console.print(f"[green]File [bold]{old}[/bold] moved to [bold]{new}[/bold]")
        else:
            console.print(f"[bold red]Error: {resp}[/bold red]")

        self.autofill_remote_refresh()

    def complete_mv(self, text, line, begidx, endidx):
        args = line.split()
        if len(args) == 2:
            return [f for f in self.remote_files if f.startswith(text)]
        return []

    def do_push(self, arg):
        "push <local> [remote]   Upload file to device"

        parts = arg.split()
        if not parts:
            console.print("[bold red]Usage: push <local> [remote][/bold red]")
            return
        local = parts[0]
        remote = parts[1] if len(parts)==2 else os.path.basename(local)

        if not os.path.isfile(local):
            console.print(f"[bold red]Local file not found: {local}[/bold red]")
            return
        size = os.path.getsize(local)

        console.print(f"[yellow]Uploading {local} as {remote} ({size} bytes)...[/yellow]")

        # with open(local,'rb') as f:
        #     checksum = crc32(f.read())

        # self.device.send_command(f"push {remote} {size} {checksum}")

        progress = Progress()
        task = progress.add_task("[cyan]Transferring file...", total=size)

        def update_progress(transferred, speed):
            speed_str = f"Speed: {speed:.2f} KB/s"
            progress.update(task, completed=transferred, description=f"[cyan]{speed_str}")

        with progress:
            with open(local,'rb') as f:
                status, resp = self.device.push(f, size, remote, update_progress)

        if status:
            console.print(f"[green]File [bold]{remote}[/bold] uploaded to device")
        else:
            console.print(f"[bold red]Error: {resp}[/bold red]")
        self.autofill_remote_refresh()

    def complete_push(self, text, line, begidx, endidx):
        parts = line.split()

        if len(parts) <= 2:
            return glob.glob(text+'*')
        elif len(parts) == 3:
            return [f for f in self.remote_files if f.startswith(text)]
        return []

    def do_pull(self, arg):
        "pull <remote> [local]  Download file from device"

        parts = arg.split()
        if not parts:
            console.print("[bold red]Usage: pull <remote> [local][/bold red]")
            return
        remote = parts[0]
        local = parts[1] if len(parts)==2 else remote

        console.print(f"[yellow]Requesting {remote}...[/yellow]")

        progress = Progress()
        task = None

        def create_task(total):
            nonlocal task
            task = progress.add_task("[cyan]Transferring file...", total=total)

        def update_progress(transferred, speed):
            speed_str = f"Speed: {speed:.2f} KB/s"
            progress.update(task, completed=transferred, description=f"[cyan]{speed_str}")

        with progress:
            with open(local,'wb') as f:
                status, resp = self.device.pull(remote, f, update_progress, create_task)

        if status:
            console.print(f"[bold green]File {local} downloaded[/bold green]")
        else:
            console.print(f"[bold red]Error: {resp}[/bold red]")

    def complete_pull(self, text, line, begidx, endidx):
        parts = line.split()
        if len(parts) <= 2:
            return [f for f in self.remote_files if f.startswith(text)]
        elif len(parts) == 3:
            return glob.glob(text+'*')
        return []

    def do_play(self, arg):
        "play <filename>     Play a remote file"
        if not arg:
            console.print("[bold red]Usage: play <filename>[/bold red]")
        elif arg not in self.remote_files:
            console.print(f"[bold red]No such file: {arg}[/bold red]")
        else:
            status, resp = self.device.play(arg)
            if status:
                console.print(f"[green]File [bold]{arg}[/bold] played")
            else:
                console.print(f"[bold red]Error: {resp}[/bold red]")

    def complete_play(self, text, line, begidx, endidx):
        return [f for f in self.remote_files if f.startswith(text)]
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

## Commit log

2025-03-27 Initial PCB versions
    [sisyphus.kicad_pcb, sisyphus.kicad_sch, sisyphus_matrix.kicad_pcb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]
2025-03-31 Add battery testing battery charger implementation Also remove unncessary tracked files
    [sisyphus.kicad_pcb, sisyphus.kicad_sch]
2025-04-02 Update main PCB
    [sisyphus.kicad_pcb, sisyphus.kicad_sch]
2025-04-02 Update 3D model
    [sisyphus.kicad_pcb]
2025-04-05 Add prototype firmware
2025-04-06 Update CMakeLists.txt Enable memory usage printing from linker Rearange and add comments Change LITTLEFS parition size definition and add a check for size
2025-04-09 Add prototype transfer protocol Protocol is still work in progress, i just wanted to write it down.
2025-04-18 Add a basic structure for USB comms and button interrupt
2025-04-26 Fix background on chip symbols
    [sisyphus.kicad_sch]
2025-04-27 Huge firmare update
    Rewrite PROTOCOL.md - with help from an LLM, MAY CONTAIN ERRORS
    Add both sides of the protocol a device side in the firmware and a
    reference python shell that can be used to test it
    Few changes to file layout
    Add a way to build and flash using `make flash`
    [main.c]
2025-04-27 Add audio playback from LFS
    The sample header is no longer needed
    [main.c]
2025-04-27 Add play command
    Move audio to a separate directory
    Remove guards and replace for `#pragma once`
    [main.c, protocol.py]
2025-04-27 Started work on 3d model also designed better spring
    [sisyphus-spring.stl, sisyphus.FCStd]
2025-04-28 Replace pico_stdio_usb with raw TinyUSB
    It wasn't as bad as i thought...
    Add reset command to protocol because we lost the native picotool one
    Add a script to automatically find the device and reset it
    [main.c, protocol.py]
2025-05-05 Make device side protocol reflect the other changes
2025-05-06 Add a static protocol indicator to `info`
    Update eternity submodule commit
    Update according docs
    Protocol version was NOT raised because of the early development stage
2025-05-13 Major PCB update
    I won't even bother commenting it
    [sisyphus.kicad_pcb, sisyphus.kicad_sch]
2025-05-14 Fix critical PCB errors
    [sisyphus.kicad_pcb, sisyphus.kicad_sch]
2025-05-14 Add some ✨flair✨ to the PCB
    [sisyphus.kicad_pcb, sisyphus.kicad_sch]
2025-05-16 Add power switch
    Minor changes
    [sisyphus.kicad_pcb, sisyphus.kicad_sch]
2025-05-18 Improved spring, now loking like its acting as clicking, started work on scalar buttons
    [sisyphus-spring.stl, sisyphus.FCStd]
2025-05-18 Some schematic readability improved. Minor changes in PCB
    [peripheral.kicad_sch, power.kicad_sch, sisyphus.kicad_pcb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]
2025-05-18 Fix things on PCB, update inductor size
    [peripheral.kicad_sch, power.kicad_sch, sisyphus.kicad_pcb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]
2025-05-18 Update things for that rendering F L A R E
    [sisyphus.kicad_pcb]
2025-05-31 Add the first actually ordered version of the PCB
    [peripheral.kicad_sch, power.kicad_sch, sisyphus.kicad_pcb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]
2025-06-02 Add the RGB sensor module
    Remove sisyphus-matrix, it was just for testing
    Move symbol library up a directory so it can be shared
    [80216oplga4l.stp, rgb_sensor.kicad_pcb, rgb_sensor.kicad_sch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]
2025-06-03 Update RGB sensor
    [rgb_sensor.kicad_pcb]
2025-06-03 Update some details about connectors
    [peripheral.kicad_sch, sisyphus.kicad_pcb]
2025-06-03 Remove debug LED
    Update eternity to a commit that also removes LED
2025-06-03 Setup for SisyFOSS β PCB
    Add a board header
    Add support for defining LFS size in board header
2025-06-11 Add I2S pins to boards
    Add default
2025-06-11 Add SisyFOSS Beta board's specific builds to actions
2025-06-12 Update reset script so devices can be flashed from Eternity
2025-06-12 Update board config with all pins
2025-06-12 Add keyboard driver
    Still doesn't decode keys to audio filenames but it is THERE
    [main.c, tca8418.c]
2025-06-17 Fixed building, added requirements for python scripts, 3D update
    [sisyphus.FCStd]
2025-06-21 Started work on charger
2025-06-21 Update RGB sensor PCB
    Redesign for a JST SH connector so it actually fits in the bezel of the keyboard matrix
    [rgb_sensor.kicad_pcb, rgb_sensor.kicad_sch]
2025-06-21 Fix 3D model path
    Add it to git and add attribution
    [SM05B-SRSS-TB.STEP, rgb_sensor.kicad_pcb]
2025-06-22 Just drop of semi tested 3D model
    [sisyphus-Bottom.stl, sisyphus-Core.stl, sisyphus-Hinge.stl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]
2025-06-22 Update RGB sensor PCB
    Just a small tweak for a manufacturing
    [rgb_sensor.kicad_pcb]
2025-07-06 Minimal Support for PIC
    [sisyphus-Top_Cover.stl]
2025-07-23 Add color sensor driver + color LUT + misc
    Generally add a lot of color related things - things for other drivers
    Add a command to read the color sensor to firmware and to python scripts
    Add a python script to visualize data from sensor
    Add a small amount of error handling, i'll rewrite it later
    Fix a few things
    [color.c, color_graph.py, main.c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]
2025-07-23 Remove an unnecessary argument that didn't break it???? What??
    [main.c]
2025-09-13 Simplify error catching
    Preparation for full error catching coverage
    [bq25619.c, bq25619.h]
2025-09-13 Add a Sisyphus debug flag to the info command
    IF IT IS NOT DO NOT SHIP THAT DEVICE OR FIRWMARE
    Also added warnings that say the same
2025-09-14 Make `error` a library and use it in color thingies
    [veml3328.c]
2025-09-14 Move color code to HSV, cleanup, a lot of docs
    Improve color reading + simple calibration (CCM in the future)
    Add RGB to HSB conversion
    Cleanup and add more error handling
    Completely rework LUT loading and parsing
    New LUT format + new color docs
    Add VEML3328 setup and trigger mode so it doesn't eat power all the time
    Add color comparison code
    Update protocol docs and update protocol related scripts accordingly
    Add a little color window to the color graph
    [color.c, color_graph.py, protocol.py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]
2025-09-14 Add playback based on button index and color code
    And it's done! This is basically all the functionality we wanted to achieve.
    There is still stuff to do. I'll start with the docs, but the code still has it's weakspots.
2025-09-14 Update READMEs, add docs, fix typos
    [color.c, main.c, plajta_sisyfoss_beta.h]
2025-09-20 Fixed error handling on color init
    This caused the LED to never get turned off
    [color.c]
2025-09-21 Fix wrongly broken behavior
    Audio just restarted when the button got clicked while playing, this was broken with Lid detection's rewrite of wakeup.
    Before this commit the audio stops, pressing a button behaves like a stop button, we don't want that tho.
    [main.c]
2025-09-21 3D improvements: Almost final version
    [sisyphus-Grille.stl, sisyphus-Hinge.stl, sisyphus-Lid.stl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]
2025-09-21 🔩 Refactored status reading in charger code
2025-09-21 Chat GPT can code even simple union 💀
2025-09-21 As I got, I also can't write simple union 💀
2025-09-21 So charger code rewrited. It is again beta, so 🔋🙏❌💣
2025-09-22 Remove unnecesary PDF from the PCBs folder
2025-09-24 3D: Final version? 🤔
    [sisyphus-Assembled-Hinge-Lid.stl, sisyphus-Core.stl, sisyphus-Grille.stl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]
2025-10-10 Some minor 3D updates
    [sisyphus-M3_spacer.stl]
2025-12-29 Lower PMIC currents on SisyFOSS Beta
    A 1A charging current could TECHNICALLY be too much for some USB ports, this could also be a cause of some of the failures we experienced.
    [plajta_sisyfoss_beta.h]
2025-12-29 Add an ARGB LED indicator (#2)
    * Add a PIO driver for RGB LED
    This is meant to serve as a status LED for the user and for debugging.
    * Add a simple prototype of a bootup sequence
    * Add optional color representation to LUT
    Also integrate it to the lightshow code
    * Fix LUT parser pointer math
    A small bugfix
    * Fix forgotten return
    * Remove unused variable
    * Redo feedback lightshow
    Now it blinks only when color is detected
    * Update docs for LED indication
    [color.c, lightshow.c, main.c]
2025-12-29 Add a calibrator script
    The script prompts the user to insert the calibration papers and automatically sends the new LUT to the device after it's done. It has some predefined colors but new ones are easy to add.
    Maybe i should also add a calibration paper generator, but that's for another day.
2026-01-10 Add white to calibrator
    Add white as a new predefined color
2026-04-05 Update .gitignore for KiCAD 10
